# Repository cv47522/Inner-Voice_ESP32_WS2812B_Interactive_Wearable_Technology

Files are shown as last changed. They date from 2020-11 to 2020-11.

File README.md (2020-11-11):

# Inner Voice

- Wearable Technology and Functional Wear Study Project.
- Materials: ESP32 / Flora RGB Smart NeoPixel / Conductive Fabrics & Yarns
- Language: Arduino
- **More details of the project (Demo Video): https://wantinghsieh.com/inner-voice**

---

## Build

**[Link to the documentation page.](https://fabacademy.wantinghsieh.com/assignment/16-wildcard-week)**

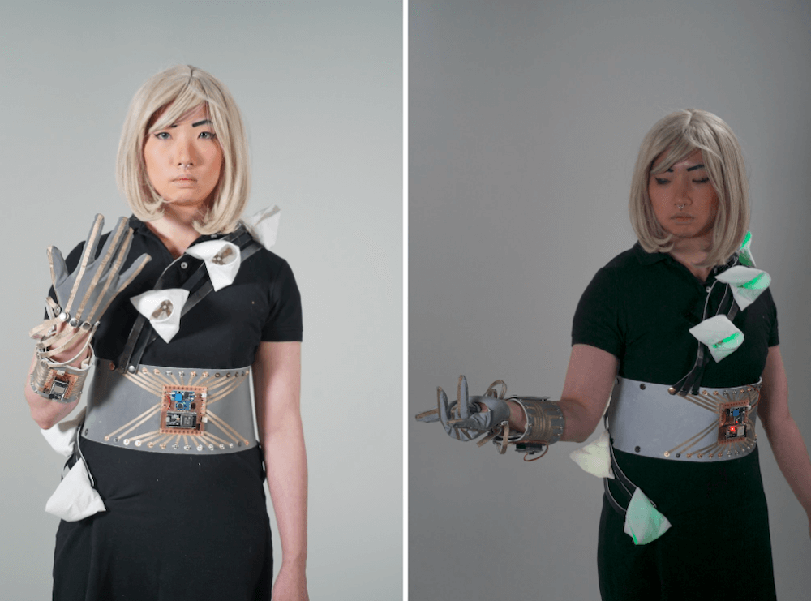
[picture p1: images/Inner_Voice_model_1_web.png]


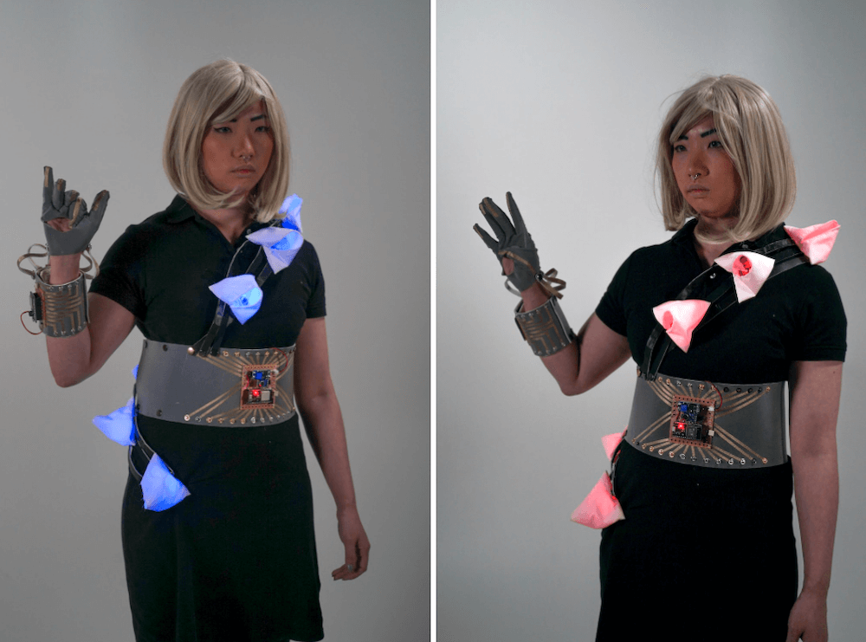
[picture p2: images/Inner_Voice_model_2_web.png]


## Belt Controller

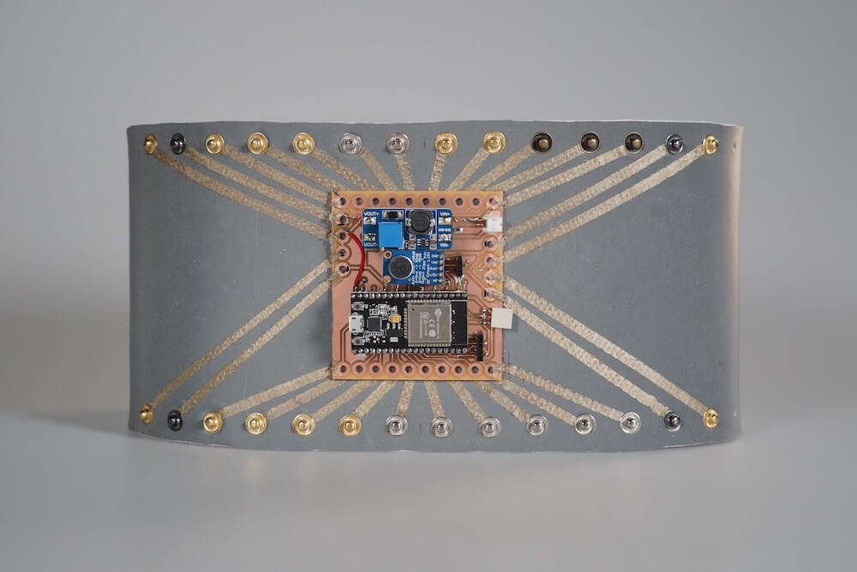
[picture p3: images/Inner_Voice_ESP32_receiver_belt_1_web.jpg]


## Bracelet Controller

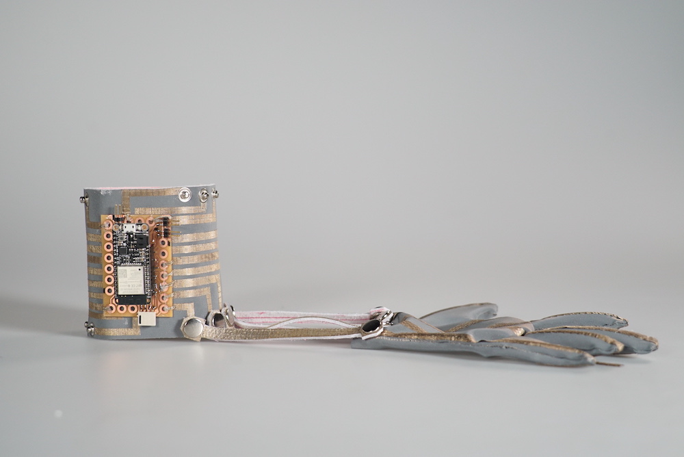
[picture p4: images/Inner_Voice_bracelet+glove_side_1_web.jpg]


## WS2812B Trianguler Light Modules

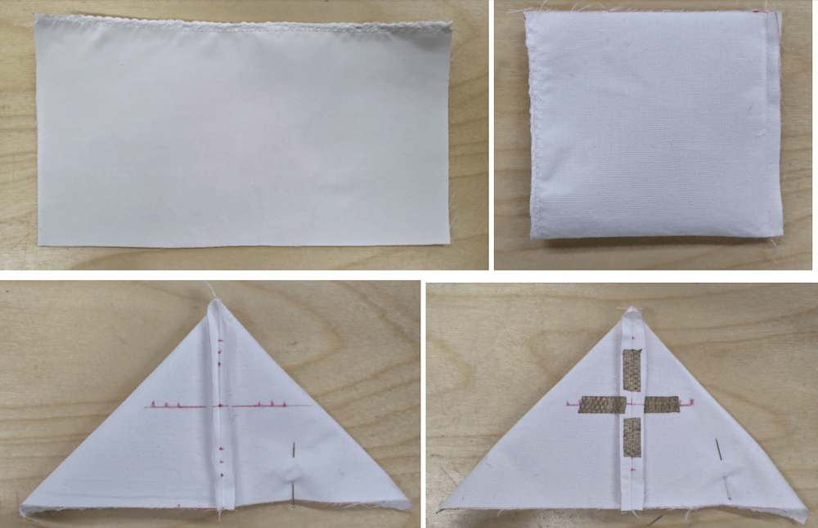
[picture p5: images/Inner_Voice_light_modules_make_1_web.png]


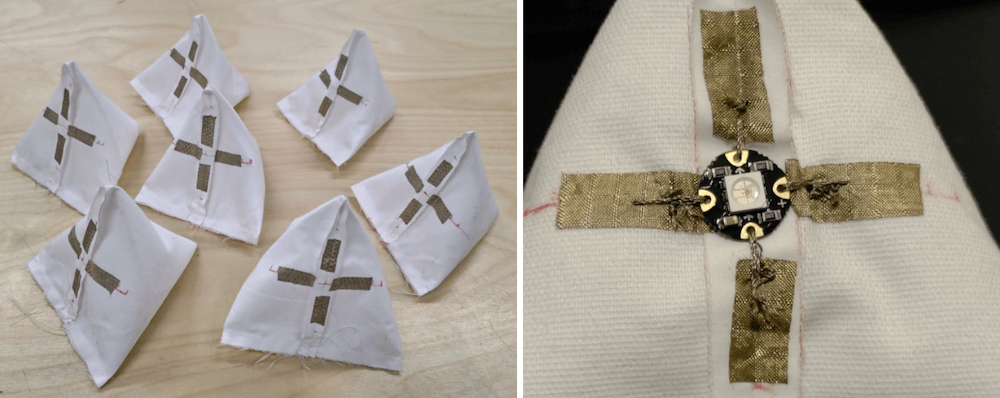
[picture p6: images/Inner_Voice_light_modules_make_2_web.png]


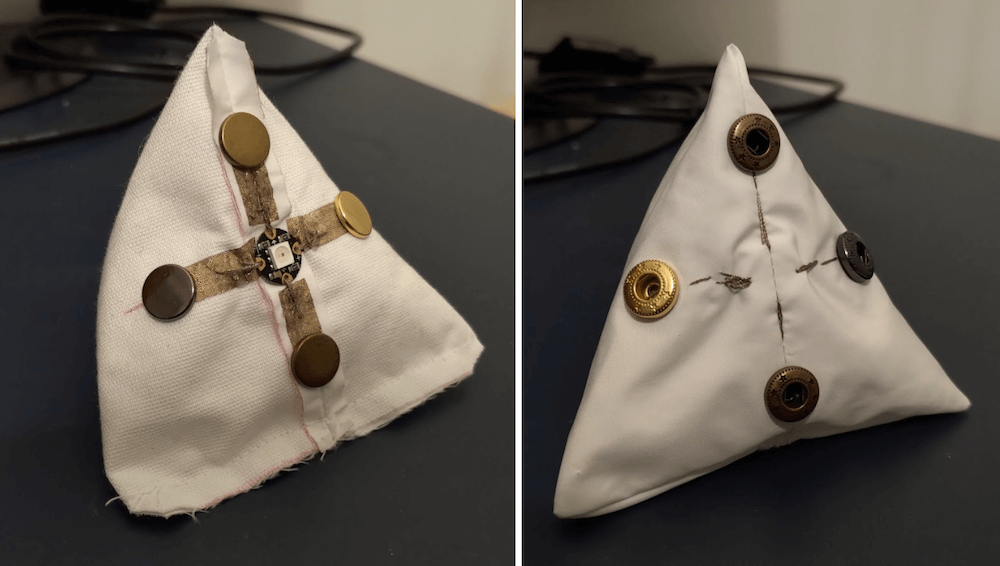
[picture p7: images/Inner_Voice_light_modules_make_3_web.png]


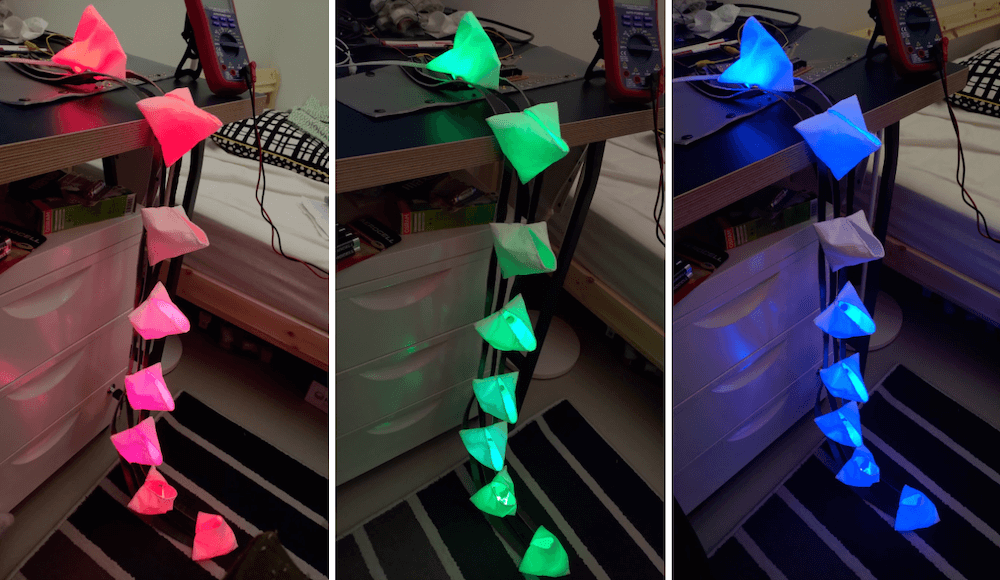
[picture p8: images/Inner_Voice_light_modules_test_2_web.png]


---

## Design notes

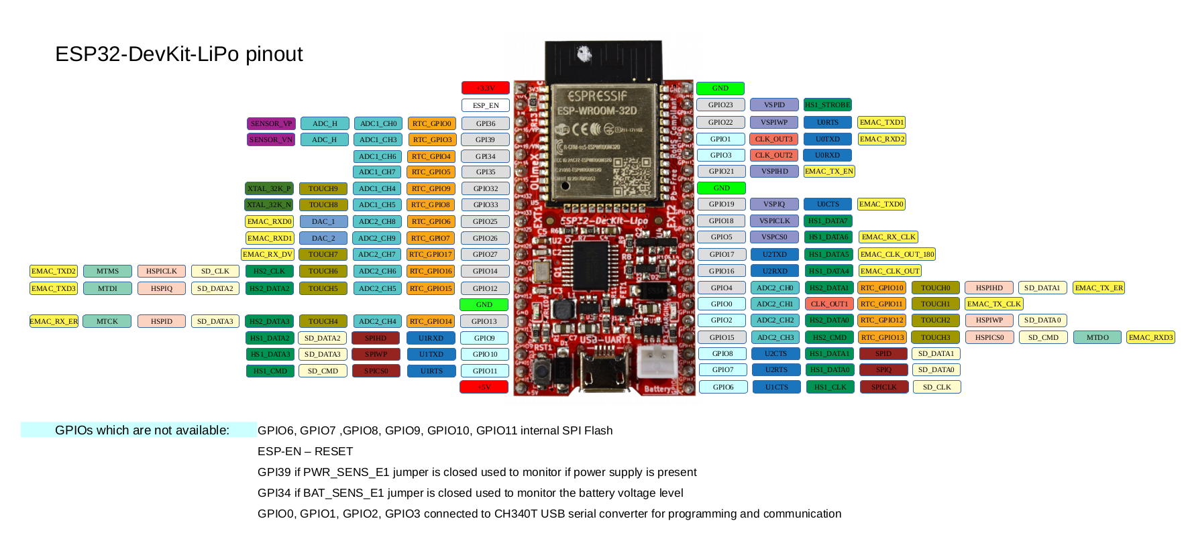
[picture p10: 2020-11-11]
pcb/KiCad-ESP32_LiPo_Wearable_Shield/doc/ESP32-DevKit-Lipo-GPIOs.png

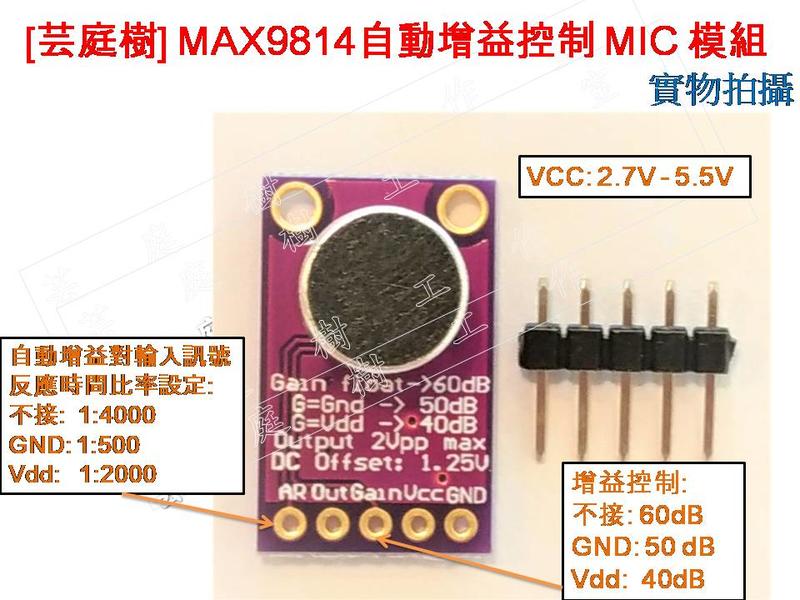
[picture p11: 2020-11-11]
pcb/KiCad-ESP32_LiPo_Wearable_Shield/doc/Max9814_Microphone.jpeg

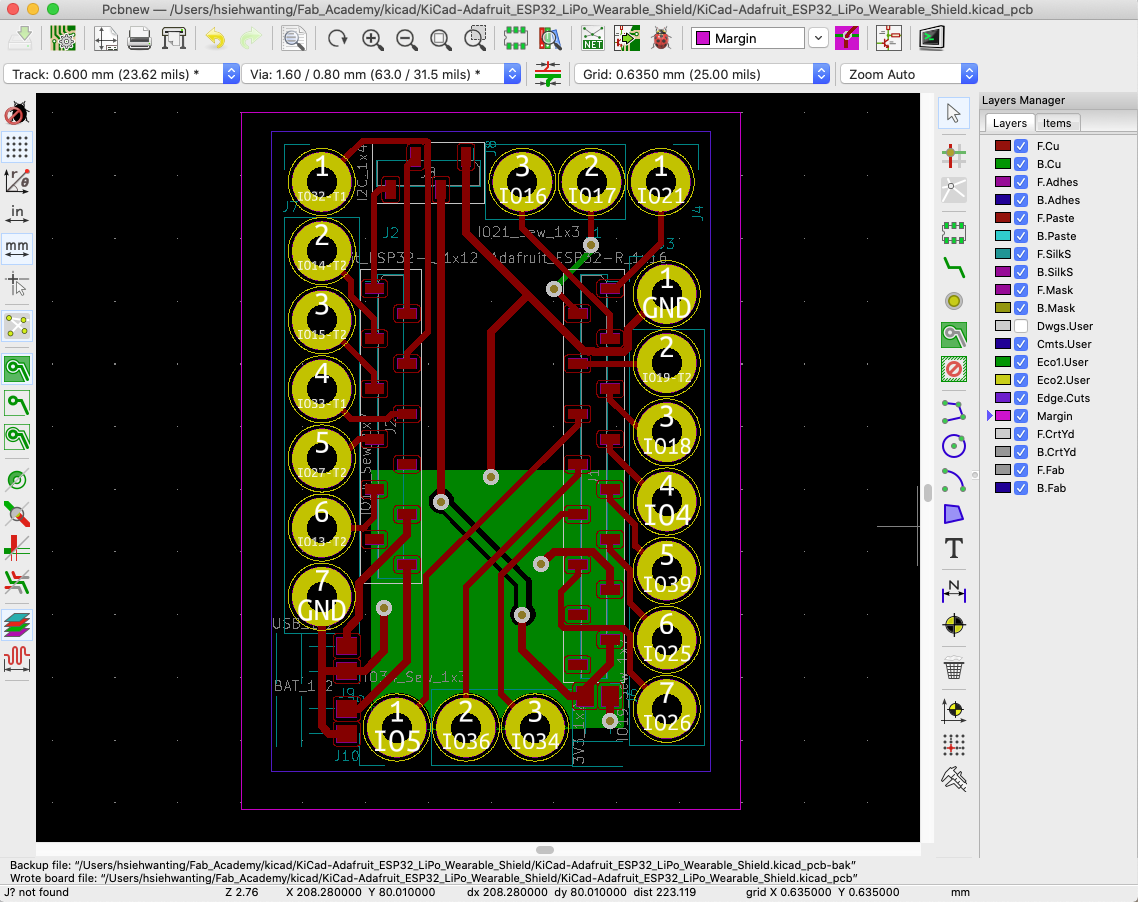
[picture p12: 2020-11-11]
pcb/KiCad-Adafruit_ESP32_LiPo_Wearable_Shield/doc/Adafruit_ESP32_Wearable_Shield_PCB.png

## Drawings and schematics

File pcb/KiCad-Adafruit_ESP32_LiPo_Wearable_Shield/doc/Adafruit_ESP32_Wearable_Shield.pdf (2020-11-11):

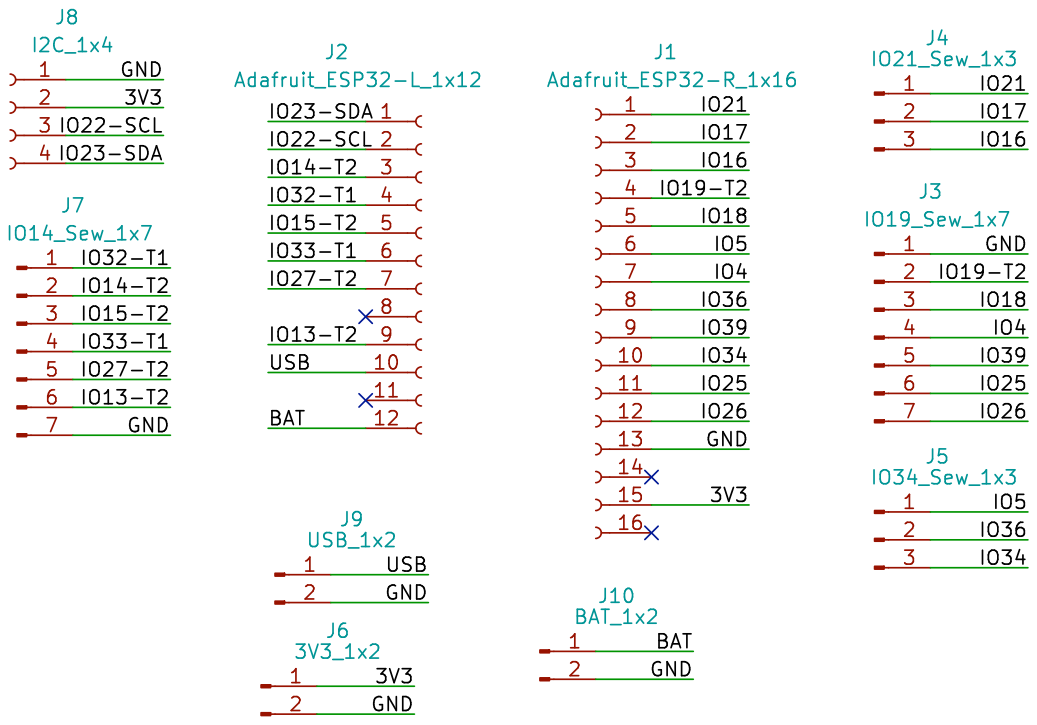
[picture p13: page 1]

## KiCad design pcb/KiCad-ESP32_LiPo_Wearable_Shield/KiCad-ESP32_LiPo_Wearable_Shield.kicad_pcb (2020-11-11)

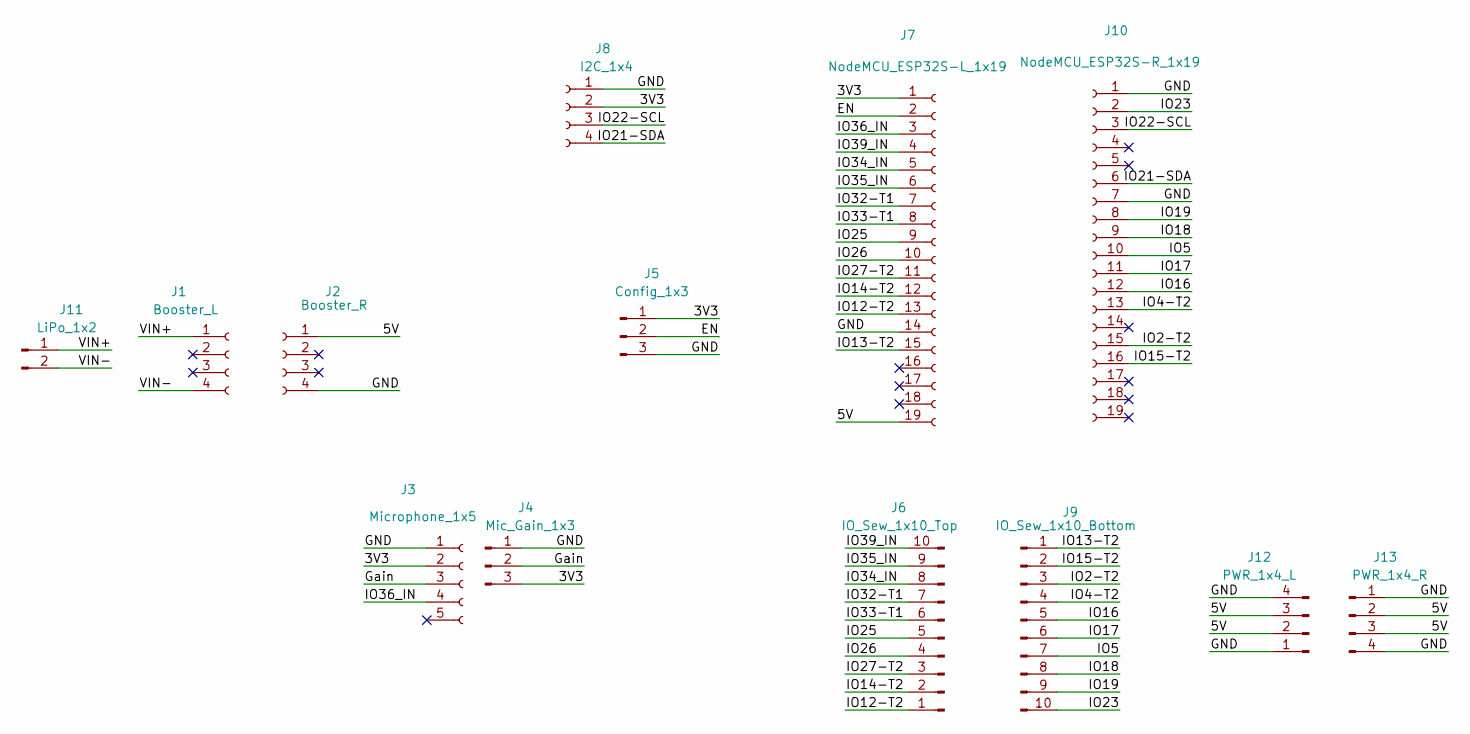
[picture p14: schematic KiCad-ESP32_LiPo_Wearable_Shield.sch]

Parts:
J1: Booster_L; PinHeader_1x04_P2.54mm_Vertical_SMD_Pin1Right
J2: Booster_R; PinHeader_1x04_P2.54mm_Vertical_SMD_Pin1Right
J3: Microphone_1x5; PinHeader_1x05_P2.54mm_Vertical_SMD_Pin1Left
J4: Mic_Gain_1x3; PinHeader_1x03_P2.54mm_Vertical_SMD_Pin1Right
J5: Config_1x3; PinHeader_1x03_P2.54mm_Vertical_SMD_Pin1Right
J6: IO_Sew_1x10_Top; PinHeader_1x10_P7mm_I3mm_Vertical
J7: NodeMCU_ESP32S-L_1x19; PinHeader_1x19_P2.54mm_Vertical_SMD_Pin1Right
J8: I2C_1x4; PinSocket_1x04_P2.54mm_Vertical_SMD_Pin1Left
J9: IO_Sew_1x10_Bottom; PinHeader_1x10_P7mm_I3mm_Vertical
J10: NodeMCU_ESP32S-R_1x19; PinHeader_1x19_P2.54mm_Vertical_SMD_Pin1Right
J11: LiPo_1x2; JST_PH_S2B-PH-K_1x02_P2.00mm_I1.5mm_Horizontal
J12: PWR_1x4_L; PinHeader_1x04_P7mm_I3mm_Vertical
J13: PWR_1x4_R; PinHeader_1x04_P7mm_I3mm_Vertical

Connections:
/3V3: J3.2, J4.3, J5.1, J7.1, J8.2
/5V: J2.1, J7.19, J12.2, J12.3, J13.2, J13.3
/EN: J5.2, J7.2
/GND: J2.4, J3.1, J4.1, J5.3, J7.14, J8.1, J10.1, J10.7, J12.1, J12.4, J13.1, J13.4
/Gain: J3.3, J4.2
/IO2-T2: J9.3, J10.15
/IO4-T2: J9.4, J10.13
/IO5: J9.7, J10.10
/IO12-T2: J6.1, J7.13
/IO13-T2: J7.15, J9.1
/IO14-T2: J6.2, J7.12
/IO15-T2: J9.2, J10.16
/IO16: J9.5, J10.12
/IO17: J9.6, J10.11
/IO18: J9.8, J10.9
/IO19: J9.9, J10.8
/IO21-SDA: J8.4, J10.6
/IO22-SCL: J8.3, J10.3
/IO23: J9.10, J10.2
/IO25: J6.5, J7.9
/IO26: J6.4, J7.10
/IO27-T2: J6.3, J7.11
/IO32-T1: J6.7, J7.7
/IO33-T1: J6.6, J7.8
/IO34_IN: J6.8, J7.5
/IO35_IN: J6.9, J7.6
/IO36_IN: J3.4, J7.3
/IO39_IN: J6.10, J7.4
/VIN+: J1.1, J11.1
/VIN-: J1.4, J11.2

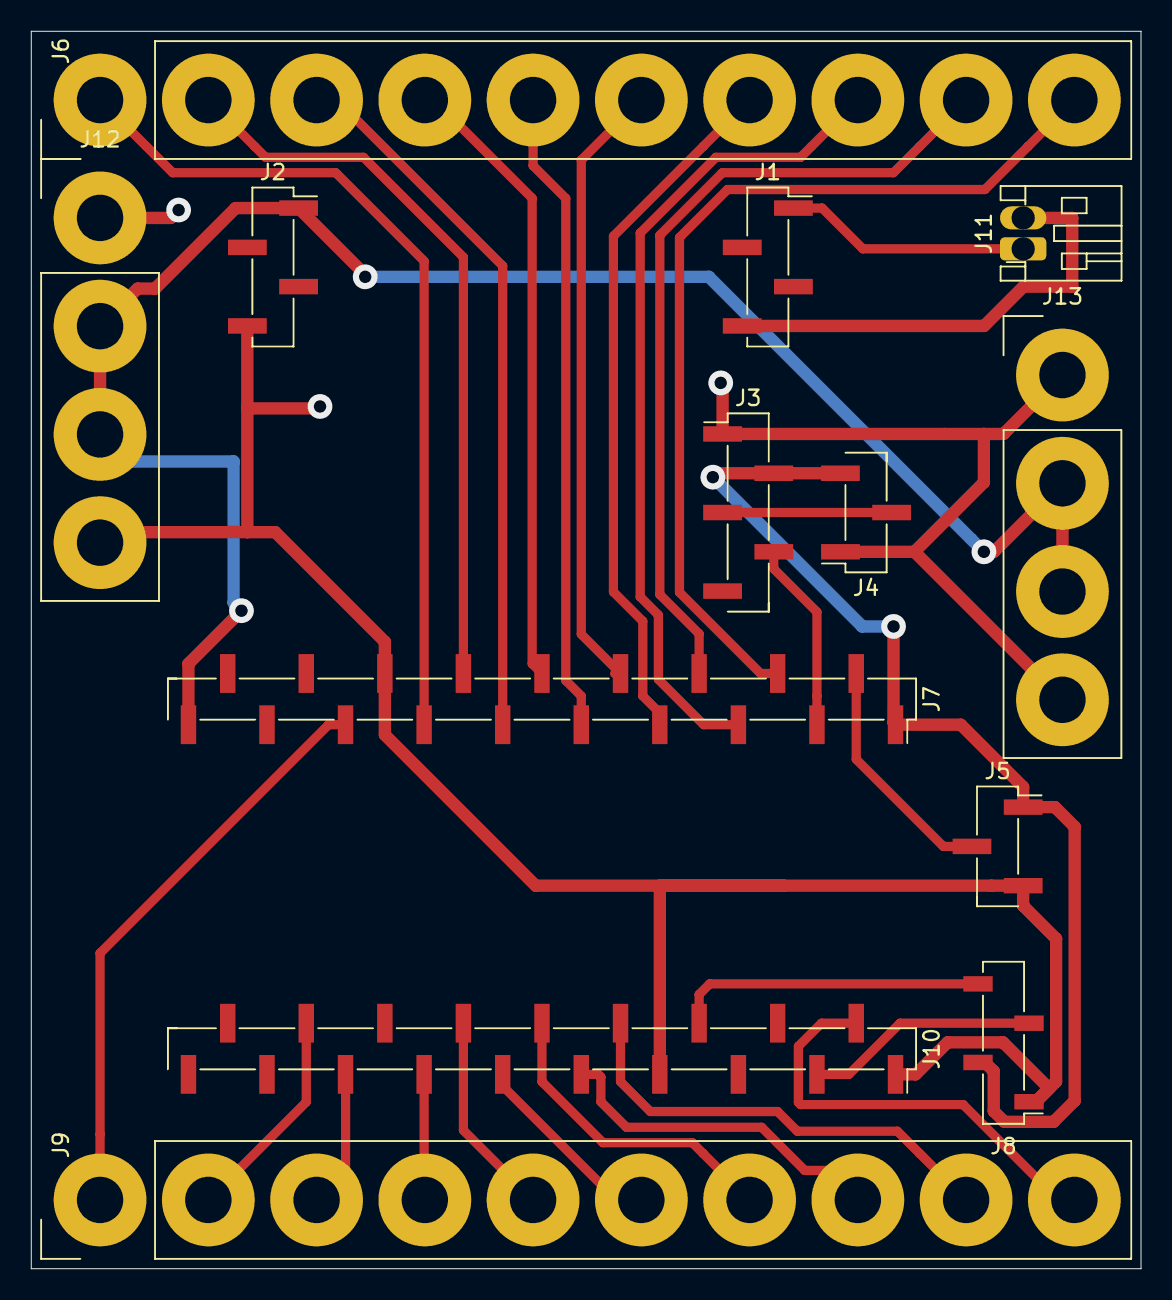
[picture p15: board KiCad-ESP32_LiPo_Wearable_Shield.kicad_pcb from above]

Board: 2 copper layers, 71.8 x 80.0 mm, 13 parts (0 on the bottom side), 30 nets.

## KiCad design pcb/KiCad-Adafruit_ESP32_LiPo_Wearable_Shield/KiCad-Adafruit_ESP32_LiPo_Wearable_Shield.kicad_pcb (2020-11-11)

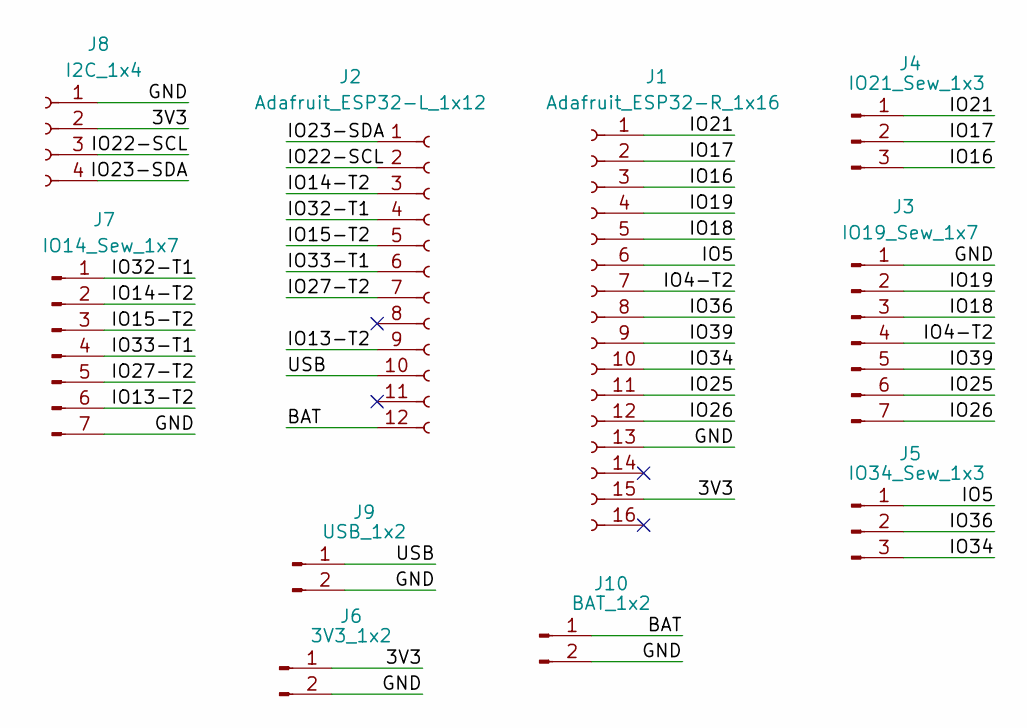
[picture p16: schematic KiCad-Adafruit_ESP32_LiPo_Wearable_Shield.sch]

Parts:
J1: Adafruit_ESP32-R_1x16; PinSocket_1x16_P2.54mm_Vertical_SMD_Pin1Right
J2: Adafruit_ESP32-L_1x12; PinSocket_1x12_P2.54mm_Vertical_SMD_Pin1Left
J3: IO19_Sew_1x7; PinHeader_1x07_P7mm_I3mm_Vertical
J4: IO21_Sew_1x3; PinHeader_1x03_P7mm_I3mm_Vertical
J5: IO34_Sew_1x3; PinHeader_1x03_P7mm_I3mm_Vertical
J6: 3V3_1x2; UPDI_Header_1x02_P2.54mm_Horizontal
J7: IO14_Sew_1x7; PinHeader_1x07_P7mm_I3mm_Vertical
J8: I2C_1x4; PinSocket_1x04_P2.54mm_Vertical_SMD_Pin1Left
J9: USB_1x2; UPDI_Header_1x02_P2.54mm_Horizontal
J10: BAT_1x2; UPDI_Header_1x02_P2.54mm_Horizontal

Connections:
/3V3: J1.15, J6.1, J8.2
/BAT: J2.12, J10.1
/GND: J1.13, J3.1, J6.2, J7.7, J8.1, J9.2, J10.2
/IO4-T2: J1.7, J3.4
/IO5: J1.6, J5.1
/IO13-T2: J2.9, J7.6
/IO14-T2: J2.3, J7.2
/IO15-T2: J2.5, J7.3
/IO16: J1.3, J4.3
/IO17: J1.2, J4.2
/IO18: J1.5, J3.3
/IO19: J1.4, J3.2
/IO21: J1.1, J4.1
/IO22-SCL: J2.2, J8.3
/IO23-SDA: J2.1, J8.4
/IO25: J1.11, J3.6
/IO26: J1.12, J3.7
/IO27-T2: J2.7, J7.5
/IO32-T1: J2.4, J7.1
/IO33-T1: J2.6, J7.4
/IO34: J1.10, J5.3
/IO36: J1.8, J5.2
/IO39: J1.9, J3.5
/USB: J2.10, J9.1

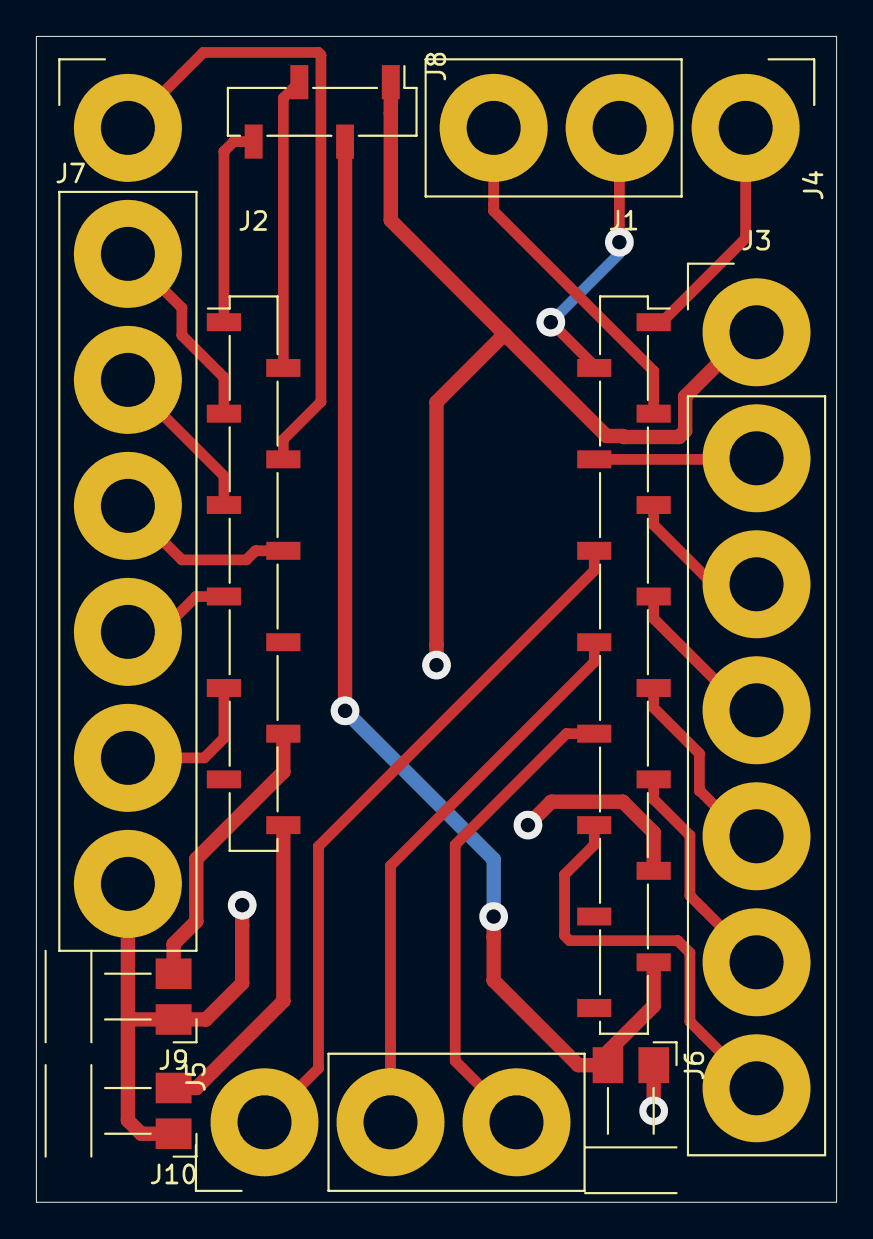
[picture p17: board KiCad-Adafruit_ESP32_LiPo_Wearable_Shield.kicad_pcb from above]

Board: 2 copper layers, 44.4 x 64.8 mm, 10 parts (0 on the bottom side), 24 nets.

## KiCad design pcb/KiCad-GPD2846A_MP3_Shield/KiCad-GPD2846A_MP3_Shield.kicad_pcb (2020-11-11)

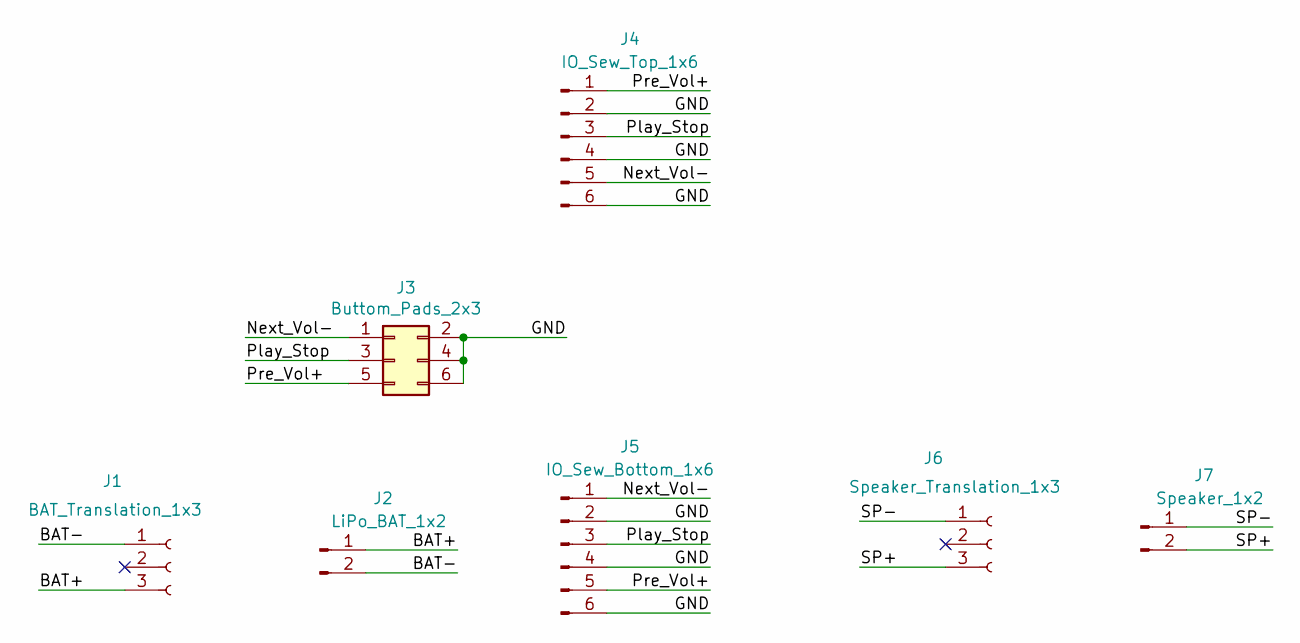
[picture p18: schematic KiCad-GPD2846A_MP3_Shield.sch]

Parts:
J1: BAT_Translation_1x3; Female_Header_1x03_P2.54mm_Horizontal
J2: LiPo_BAT_1x2; JST_PH_S2B-PH-K_1x02_P2.00mm_I1.5mm_Horizontal
J3: Buttom_Pads_2x3; PinHeader_2x03_P2.54mm_Vertical_SMD
J4: IO_Sew_Top_1x6; PinHeader_1x06_P7mm_I3mm_Vertical
J5: IO_Sew_Bottom_1x6; PinHeader_1x06_P7mm_I3mm_Vertical
J6: Speaker_Translation_1x3; Female_Header_1x03_P2.54mm_Horizontal
J7: Speaker_1x2; Term_Block_1x2_P5mm_I1.5mm

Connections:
/BAT+: J1.3, J2.1
/BAT-: J1.1, J2.2
/GND: J3.2, J3.4, J3.6, J4.2, J4.4, J4.6, J5.2, J5.4, J5.6
/Next_Vol-: J3.1, J4.5, J5.1
/Play_Stop: J3.3, J4.3, J5.3
/Pre_Vol+: J3.5, J4.1, J5.5
/SP+: J6.3, J7.2
/SP-: J6.1, J7.1

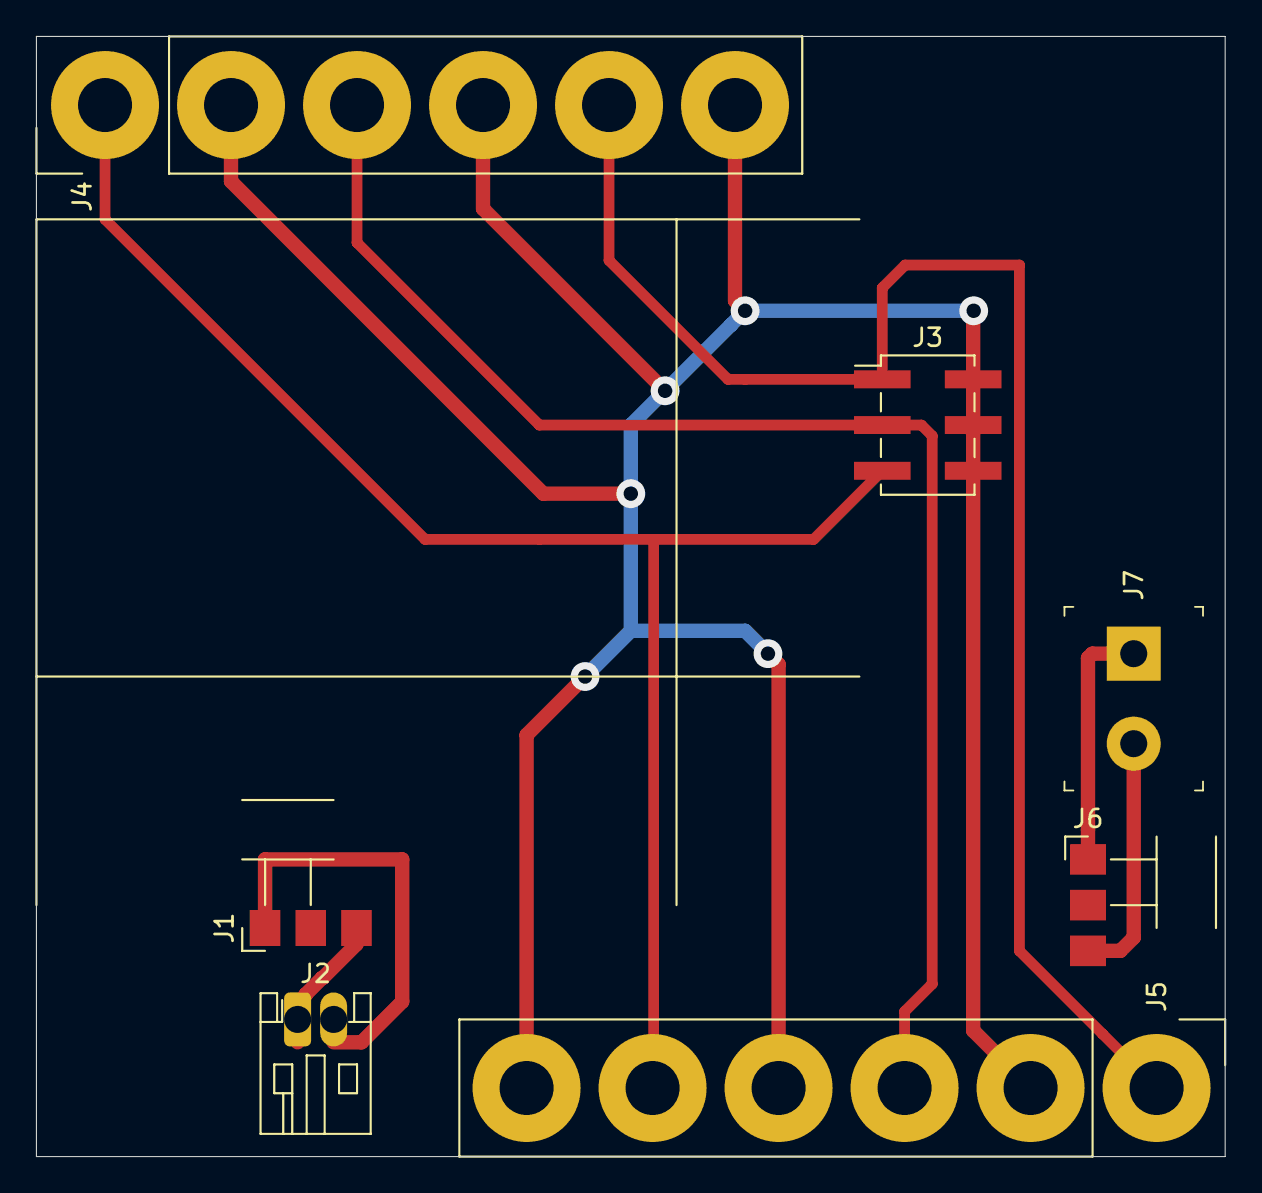
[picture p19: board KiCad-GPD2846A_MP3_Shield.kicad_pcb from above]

Board: 2 copper layers, 66.0 x 62.2 mm, 7 parts (0 on the bottom side), 8 nets.

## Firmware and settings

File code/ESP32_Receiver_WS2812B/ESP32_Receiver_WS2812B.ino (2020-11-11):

/*
  Rui Santos
  Complete project details at https://RandomNerdTutorials.com/esp-now-esp32-arduino-ide/
  
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
  The above copyright notice and this permission notice shall be included in all
  copies or substantial portions of the Software.
*/

#include <esp_now.h>
#include <WiFi.h>
#include <analogWrite.h>

int fingerData[5] = {0}; // THUMB, POINTER, MIDDLE_FINGER, RING_FINGER, PINKY
const int threshold = 23;

#include <FastLED.h>
//#define MAX_POWER_MILLIAMPS 500
#define BRIGHTNESS          150
#define NUM_LEDS 8
#define DATA_PIN 12 
CRGB leds[NUM_LEDS];

#define UPDATES_PER_SECOND 100
CRGBPalette16 currentPalette;
TBlendType    currentBlending;

extern CRGBPalette16 myRedWhiteBluePalette;
extern const TProgmemPalette16 myRedWhiteBluePalette_p PROGMEM;


// callback function that will be executed when data is received
void OnDataRecv(const uint8_t * mac, const uint8_t *incomingData, int len) {
  memcpy(&fingerData, incomingData, sizeof(fingerData));
  // this for loop works correctly with an array of any type or size
  for (byte i = 0; i < (sizeof(fingerData) / sizeof(fingerData[0])); i++) {
    Serial.print("Get Finger ");
    Serial.print(i+1);
    Serial.print(": ");
    Serial.println(fingerData[i]);
  }

  if (fingerData[0] <= threshold && fingerData[1] > threshold && fingerData[2] > threshold && fingerData[3] > threshold && fingerData[4] > threshold) {
    for (int i=0; i<NUM_LEDS; i++) {
      leds[i] = CRGB::Red;
      FastLED.show();
    }
  }else if (fingerData[1] <= threshold && fingerData[0] > threshold && fingerData[2] > threshold && fingerData[3] > threshold && fingerData[4] > threshold) {
    for (int i=0; i<NUM_LEDS; i++) {
      leds[i] = CRGB::Blue;
      FastLED.show();
    }
  }else if (fingerData[2] <= threshold && fingerData[0] > threshold && fingerData[1] > threshold && fingerData[3] > threshold && fingerData[4] > threshold) {
    for (int i=0; i<NUM_LEDS; i++) {
      leds[i] = CRGB::Green;
      FastLED.show();
    }
  }else if (fingerData[3] <= threshold && fingerData[0] > threshold && fingerData[1] > threshold && fingerData[2] > threshold && fingerData[4] > threshold) {
    for (int i=0; i<NUM_LEDS; i++) {
      leds[i] = CRGB::Yellow;
      FastLED.show();
    }
  }else if (fingerData[4] <= threshold && fingerData[0] > threshold && fingerData[1] > threshold && fingerData[2] > threshold && fingerData[3] > threshold) {
    for (int i=0; i<NUM_LEDS; i++) {
      leds[i] = CRGB::Pink;// Green, Blue, Red
      FastLED.show();
    }
  }// FirstLight
  else if (fingerData[1] <= threshold && fingerData[3] <= threshold && fingerData[0] > threshold && fingerData[2] > threshold && fingerData[4] > threshold) {
    for(int whiteLed = 0; whiteLed < NUM_LEDS; whiteLed = whiteLed + 1) {
      leds[whiteLed] = CRGB::White;
      FastLED.show();
      delay(100);
      leds[whiteLed] = CRGB::Black;
   }
  }// ColorPalette
  else if (fingerData[2] <= threshold && fingerData[3] <= threshold && fingerData[0] > threshold && fingerData[1] > threshold && fingerData[4] > threshold) {
    ChangePalettePeriodically();
    
    static uint8_t startIndex = 0;
    startIndex = startIndex + 1; /* motion speed */
    
    FillLEDsFromPaletteColors( startIndex);
    
    FastLED.show();
    FastLED.delay(1000 / UPDATES_PER_SECOND);
  }// Cylon
  else if (fingerData[1] <= threshold && fingerData[2] <= threshold && fingerData[3] <= threshold && fingerData[0] > threshold && fingerData[4] > threshold) {
    static uint8_t hue = 0;
    for(int i = 0; i < NUM_LEDS; i++) {
      leds[i] = CHSV(hue++, 255, 255);
      FastLED.show(); 
      fadeall();
      delay(10);
    }
    for(int i = (NUM_LEDS)-1; i >= 0; i--) {
      leds[i] = CHSV(hue++, 255, 255);
      FastLED.show();
      fadeall();
      delay(10);
    }
  }else {
    for (int i=0; i<NUM_LEDS; i++) {
      leds[i] = CRGB::Black;
      FastLED.show();
    }
  }
}
 
void setup() {
  FastLED.addLeds<WS2812B, DATA_PIN, GRB>(leds, NUM_LEDS);  // GRB ordering is typical
//  FastLED.setMaxPowerInVoltsAndMilliamps(5, MAX_POWER_MILLIAMPS);
  FastLED.setBrightness(BRIGHTNESS);
  
  currentPalette = RainbowColors_p;
  currentBlending = LINEARBLEND;
    
  // Initialize Serial Monitor
  Serial.begin(115200);
  
  // Set device as a Wi-Fi Station
  WiFi.mode(WIFI_STA);

  // Init ESP-NOW
  if (esp_now_init() != ESP_OK) {
    Serial.println("Error initializing ESP-NOW");
    return;
  }
  
  // Once ESPNow is successfully Init, we will register for recv CB to
  // get recv packer info
  esp_now_register_recv_cb(OnDataRecv);
}
 
void loop() {

}
void fadeall() { for(int i = 0; i < NUM_LEDS; i++) { leds[i].nscale8(250); } }

void FillLEDsFromPaletteColors( uint8_t colorIndex)
{
    uint8_t brightness = 255;
    
    for( int i = 0; i < NUM_LEDS; i++) {
        leds[i] = ColorFromPalette( currentPalette, colorIndex, brightness, currentBlending);
        colorIndex += 3;
    }
}

void ChangePalettePeriodically()
{
    uint8_t secondHand = (millis() / 1000) % 60;
    static uint8_t lastSecond = 99;
    
    if( lastSecond != secondHand) {
        lastSecond = secondHand;
        if( secondHand ==  0)  { currentPalette = RainbowColors_p;         currentBlending = LINEARBLEND; }
        if( secondHand == 10)  { currentPalette = RainbowStripeColors_p;   currentBlending = NOBLEND;  }
        if( secondHand == 15)  { currentPalette = RainbowStripeColors_p;   currentBlending = LINEARBLEND; }
        if( secondHand == 20)  { SetupPurpleAndGreenPalette();             currentBlending = LINEARBLEND; }
        if( secondHand == 25)  { SetupTotallyRandomPalette();              currentBlending = LINEARBLEND; }
        if( secondHand == 30)  { SetupBlackAndWhiteStripedPalette();       currentBlending = NOBLEND; }
        if( secondHand == 35)  { SetupBlackAndWhiteStripedPalette();       currentBlending = LINEARBLEND; }
        if( secondHand == 40)  { currentPalette = CloudColors_p;           currentBlending = LINEARBLEND; }
        if( secondHand == 45)  { currentPalette = PartyColors_p;           currentBlending = LINEARBLEND; }
        if( secondHand == 50)  { currentPalette = myRedWhiteBluePalette_p; currentBlending = NOBLEND;  }
        if( secondHand == 55)  { currentPalette = myRedWhiteBluePalette_p; currentBlending = LINEARBLEND; }
    }
}

void SetupTotallyRandomPalette()
{
    for( int i = 0; i < 16; i++) {
        currentPalette[i] = CHSV( random8(), 255, random8());
    }
}

void SetupBlackAndWhiteStripedPalette()
{
    // 'black out' all 16 palette entries...
    fill_solid( currentPalette, 16, CRGB::Black);
    // and set every fourth one to white.
    currentPalette[0] = CRGB::White;
    currentPalette[4] = CRGB::White;
    currentPalette[8] = CRGB::White;
    currentPalette[12] = CRGB::White;
    
}

void SetupPurpleAndGreenPalette()
{
    CRGB purple = CHSV( HUE_PURPLE, 255, 255);
    CRGB green  = CHSV( HUE_GREEN, 255, 255);
    CRGB black  = CRGB::Black;
    
    currentPalette = CRGBPalette16(
                                   green,  green,  black,  black,
                                   purple, purple, black,  black,
                                   green,  green,  black,  black,
                                   purple, purple, black,  black );
}

const TProgmemPalette16 myRedWhiteBluePalette_p PROGMEM =
{
    CRGB::Red,
    CRGB::Gray, // 'white' is too bright compared to red and blue
    CRGB::Blue,
    CRGB::Black,
    
    CRGB::Red,
    CRGB::Gray,
    CRGB::Blue,
    CRGB::Black,
    
    CRGB::Red,
    CRGB::Red,
    CRGB::Gray,
    CRGB::Gray,
    CRGB::Blue,
    CRGB::Blue,
    CRGB::Black,
    CRGB::Black
};

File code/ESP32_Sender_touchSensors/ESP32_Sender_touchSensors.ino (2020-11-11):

/*
  Rui Santos
  Complete project details at https://RandomNerdTutorials.com/esp-now-esp32-arduino-ide/
  
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
  The above copyright notice and this permission notice shall be included in all
  copies or substantial portions of the Software.
*/

#include <esp_now.h>
#include <WiFi.h>

// REPLACE WITH YOUR RECEIVER MAC Address
uint8_t broadcastAddress[] = {0x24, 0x6F, 0x28, 0x7A, 0xA0, 0xF4};

#define THUMB 27 //ADC pin: analog (0-4095)
#define POINTER 32
#define MIDDLE_FINGER 15
#define RING_FINGER 14
#define PINKY 33

const int touchPinArray[5] = {THUMB, POINTER, MIDDLE_FINGER, RING_FINGER, PINKY};
int touchValInArray[5] = {0};
int touchValOutArray[5] = {0};

//const int threshold = 35;
const int rangeMax = 25; //25, 40
const int rangeMin = 0; //20

// callback when data is sent
void OnDataSent(const uint8_t *mac_addr, esp_now_send_status_t status) {
  Serial.print("\r\nLast Packet Send Status:\t");
  Serial.println(status == ESP_NOW_SEND_SUCCESS ? "Delivery Success" : "Delivery Fail");
}
 
void setup() {
  // Init Serial Monitor
  Serial.begin(115200);
 
  // Set device as a Wi-Fi Station
  WiFi.mode(WIFI_STA);

  // Init ESP-NOW
  if (esp_now_init() != ESP_OK) {
    Serial.println("Error initializing ESP-NOW");
    return;
  }

  // Once ESPNow is successfully Init, we will register for Send CB to
  // get the status of Trasnmitted packet
  esp_now_register_send_cb(OnDataSent);
  
  // Register peer
  esp_now_peer_info_t peerInfo;
  memcpy(peerInfo.peer_addr, broadcastAddress, 6);
  peerInfo.channel = 0;  
  peerInfo.encrypt = false;
  
  // Add peer        
  if (esp_now_add_peer(&peerInfo) != ESP_OK){
    Serial.println("Failed to add peer");
    return;
  }
}
 
void loop() {
  // this for loop works correctly with an array of any type or size
  for (byte i = 0; i < (sizeof(touchPinArray) / sizeof(touchPinArray[0])); i++) {
    touchValInArray[i] = touchRead(touchPinArray[i]);
//    touchValInArray[i] = (touchRead(touchPinArray[i]) > rangeMax) ? rangeMax : touchRead(touchPinArray[i]);
    touchValOutArray[i] = map(touchValInArray[i], rangeMax, rangeMin, 0, 255);
    Serial.print("Send Finger ");
    Serial.print(i+1);
    Serial.print(": ");
    Serial.println(touchValInArray[i]);
  }
  
//  thumbValIn = (touchRead(THUMB) > rangeMax) ? rangeMax : thumbValIn;
//  // map it to the range of the analog out:
////  thumbValueIn = map(thumbValueIn, 0, 4095, 0, 255);
//  thumbValOut = map(thumbValIn, rangeMax, rangeMin, 0, 255);
 
  // Send message via ESP-NOW
  esp_err_t result = esp_now_send(broadcastAddress, (uint8_t *) &touchValInArray, sizeof(touchValInArray));
//  esp_err_t result = esp_now_send(broadcastAddress, (uint8_t *) &touchValOutArray, sizeof(touchValOutArray));
   
  if (result == ESP_OK) {
    Serial.print("Sent with success, Button State: ");
  }
  else {
    Serial.println("Error sending the data");
  }

//  Serial.println(thumbValOut);
//  Serial.println(thumbValIn);
  delay(200);
}
